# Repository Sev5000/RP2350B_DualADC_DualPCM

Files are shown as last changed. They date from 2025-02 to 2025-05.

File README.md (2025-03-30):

# RP2350B_DualADC_DualPCM
This is a PCB to neatly package a RP2350B, two AD9226 ADC PCBs and two PCM1802 audio boards for capture with hsdaoh.
Specifically designed to still be usefull without smds (no head switch input then). Through-hole soldering only works just fine.

For use with [https://github.com/steve-m/hsdaoh-rp2350/tree/pcm1802](https://github.com/steve-m/hsdaoh/tree/dual_12bit_adc)

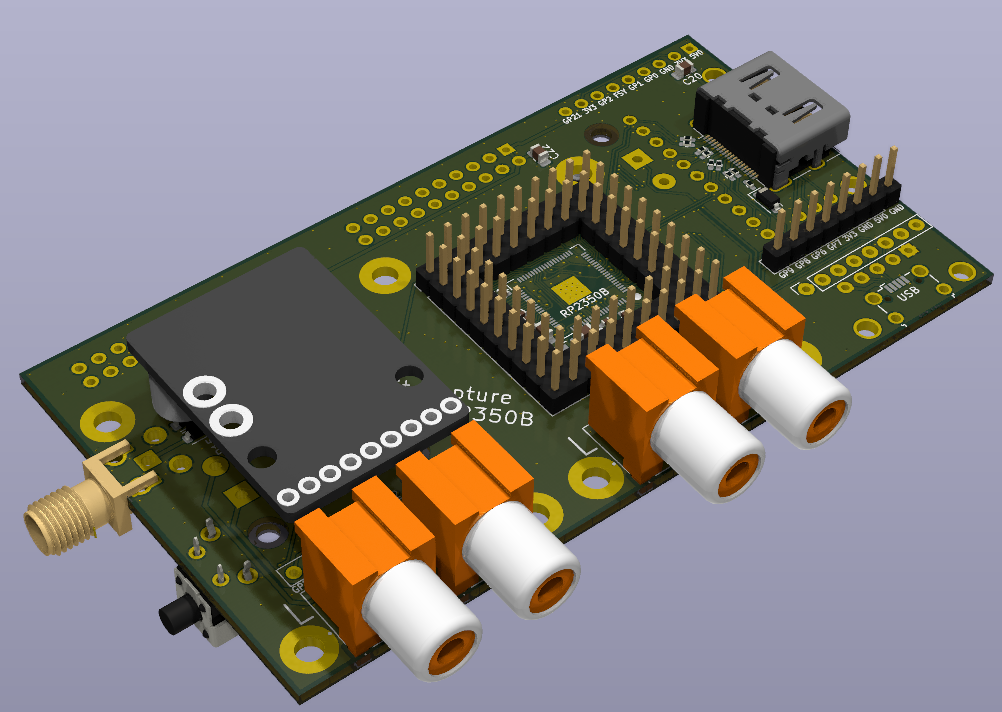
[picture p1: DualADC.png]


Features:
- Two 12bit 40MS/s ADCs
- Four channel audio input all with a common clock
- No SMD soldering needed! Works fine just connecting breakout boards
- Socket for a Pimoroni PGA2350 and RP2350 and its periphery
- The protected head switch input has footprints for edge and horizontal SMA/SMB (SMD soldering needed)
- Socket for USB C and Micro B breakouts
  
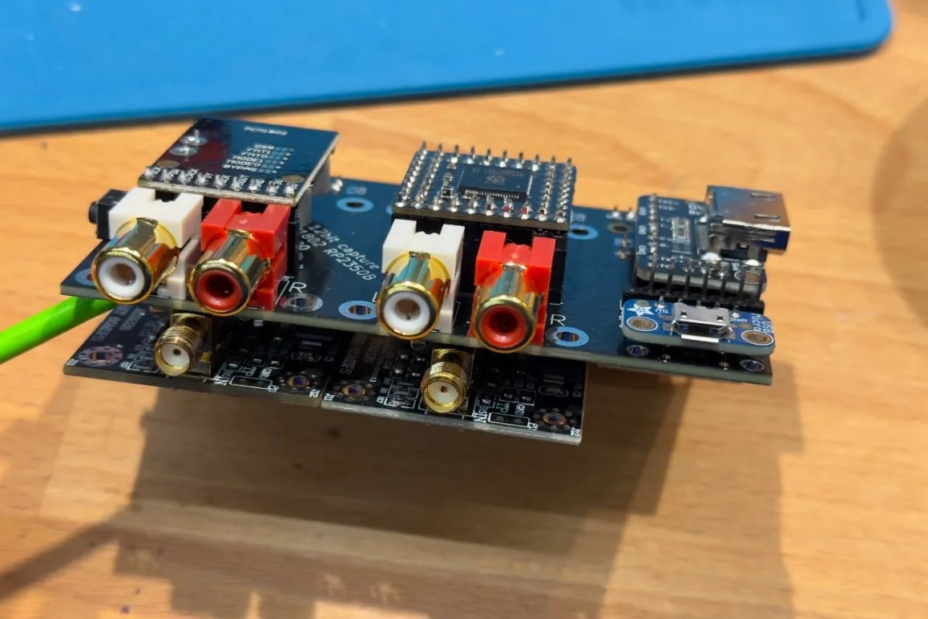
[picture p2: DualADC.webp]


Bill of material: 
- 1x This PCB (Send the Gerber .zip to JLC, PCBWay, ..)
- 1x Pimoroni PGA2350
- 2x AD9226: https://aliexpress.com/item/1005003038271519.html
- 2x PCM1802: https://aliexpress.com/item/1005006412873984.html
- 4x RCA-105 or RCA-106: https://aliexpress.com/item/1005006152724809.html
- 2x 9pin 2.54mm pin-socket header 
- 2x 2x10pin 2.54mm pin-socket header
- 2x 3pin 2.54mm pin header (remove the center pin for connecting R/L of the PCM1802)
- 2x 3pin 2.54mm pin-socket header (remove the center pin for connecting R/L of the PCM1802)
- 1x vertical 6mm push button: https://aliexpress.com/item/1005005831153897.html (horizontal soldered in vertical and a drop of glue for stability works as well)

No SMD variant:
- 1x Adafruit DVI breakout board
- 4x 2x8pin 2.54mm pin-socket header
- Either Adafruit USB Micro-B Breakout Board or Adafruit USB C Breakout Board

SMD Variant with PGA2350:
- Regular HDMI connector
- micro USB connector
- 8× 0402 270 ohm resistors
- 4x 0805 100nF ceramic capacitors
- For experimental EDID communication and HPD: 4x SOD123 3.3V Zener, 4x 0402 ~27 ohm resistors, 2x 0402 2k2 ohm resistors

For head switch input:
- 1x SOD123 3.3V zener diode
- 1x SOD123 standard diode
- 1x 0805 1k resistor
- 1x edge SMA/SMB or horizontal SMA/SMB and/or 2pin header

Notes:
- Soldering the RP2350B and its periphery might work but was not tested so far.
- The PCM1802 board needs MODE0 (MODE1 only with previous HSDAOH releases) bridged *and* connected to 3.3V with a wire (Those boards have a design error):
NOTE: Picture shows the configuration for the older firmware, now only MODE0 needs to be bridged and connected to 3.3V



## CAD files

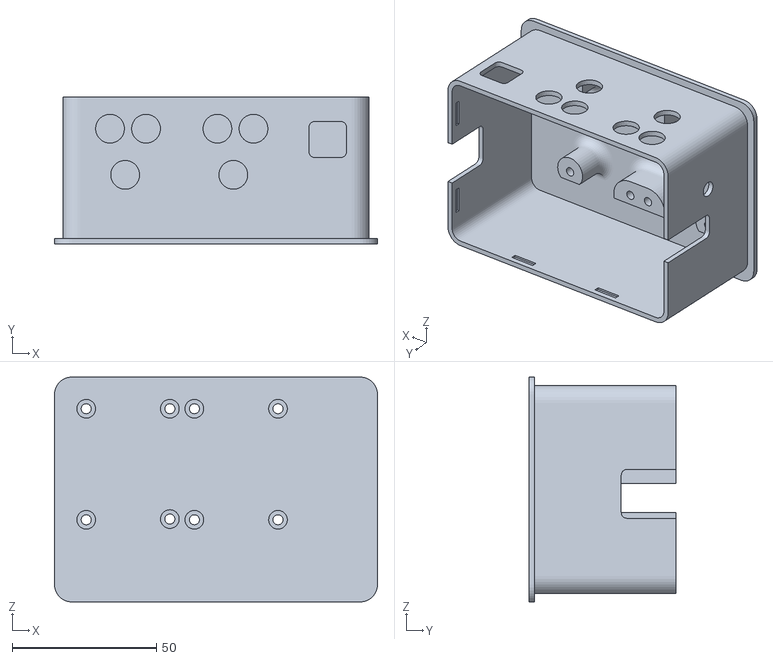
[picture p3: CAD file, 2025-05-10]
Case/RPi2350_Dual_Base.stl
112.0 x 51.0 x 78.0

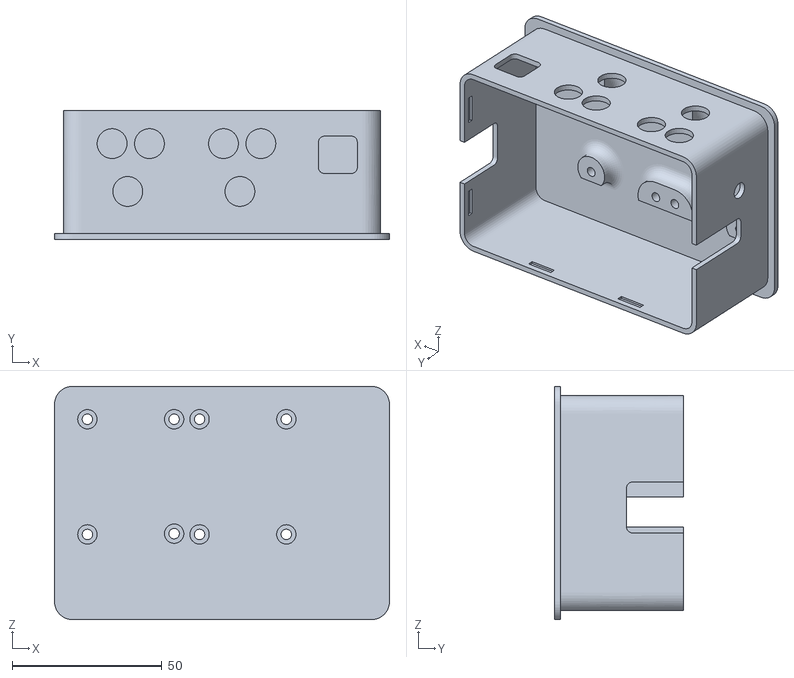
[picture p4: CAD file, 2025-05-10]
Case/RPi2350_Dual_Base_LowProfile.stl
112.0 x 43.0 x 78.0

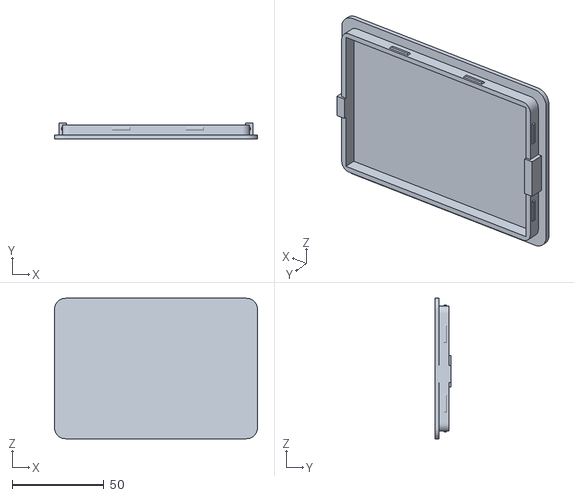
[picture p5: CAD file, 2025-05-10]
Case/RPi2350_Dual_Lid.stl
110.5 x 8.50 x 76.5

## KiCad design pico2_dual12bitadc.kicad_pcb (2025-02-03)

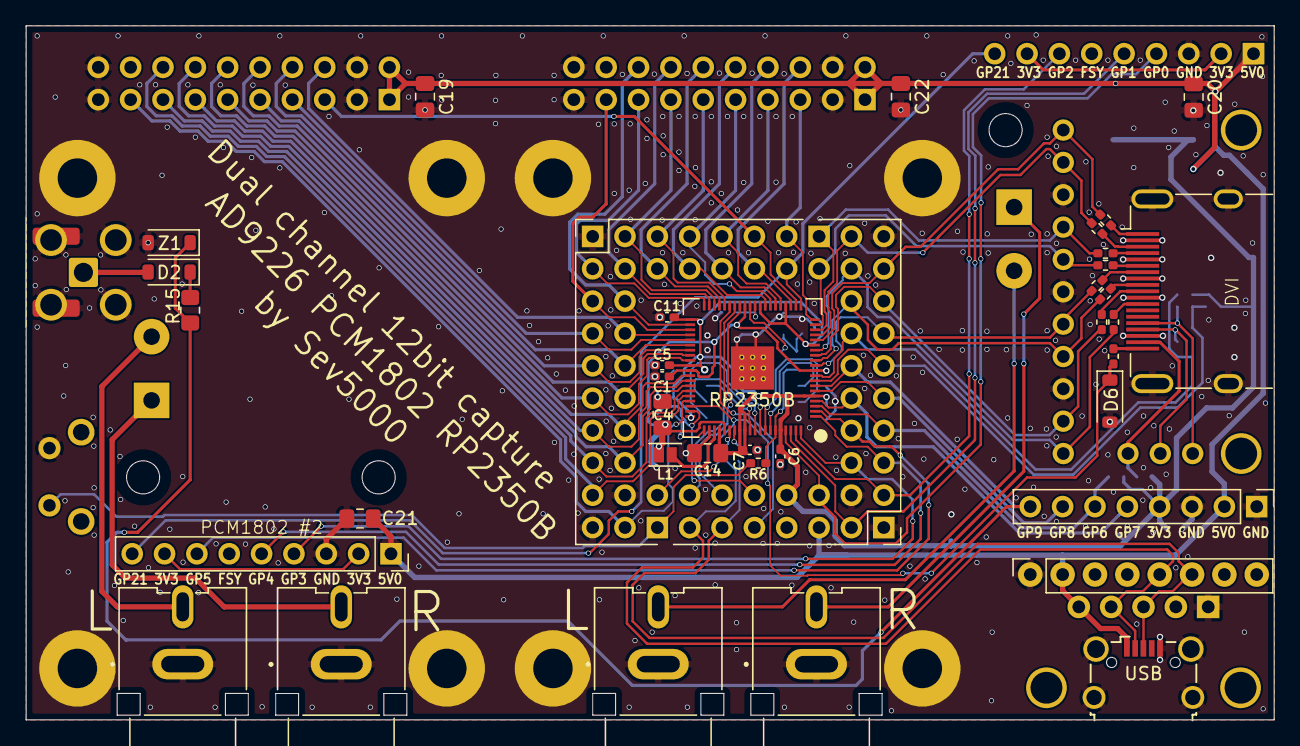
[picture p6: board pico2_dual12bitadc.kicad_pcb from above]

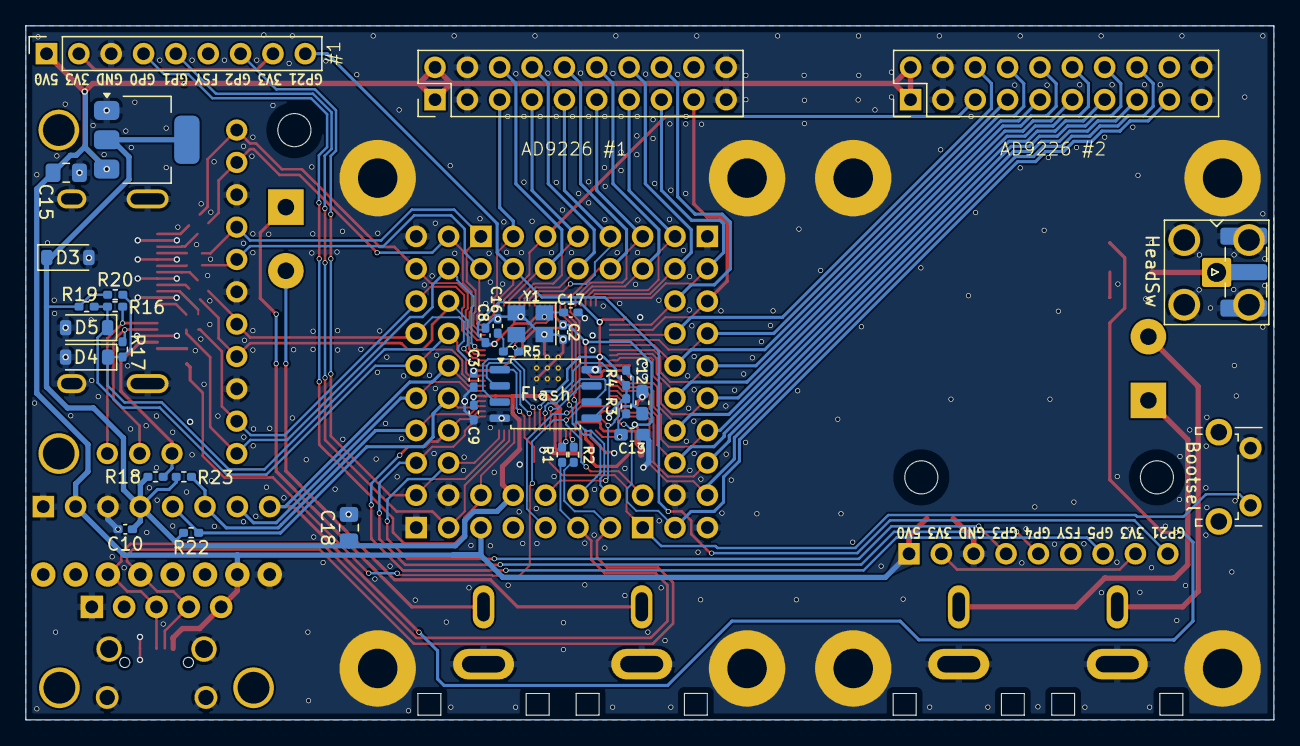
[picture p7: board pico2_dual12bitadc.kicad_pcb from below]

Board: 2 copper layers, 98.0 x 54.5 mm, 75 parts (34 on the bottom side), 89 nets.

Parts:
AD9226 #1: AD9226 #1; AD9226 PCB
AD9226 #2: AD9226 #2; AD9226 PCB
Bootsel: SW_Push; SW_Tactile_SPST_Angled_PTS645Vx58-2LFS
C1, C2, C3, C5, C6, C7, C8, C9, C10, C11: 100nF; C_0402_1005Metric_Pad0.74x0.62mm_HandSolder
C4, C14, C15: 10uF; C_0805_2012Metric_Pad1.18x1.45mm_HandSolder
C12, C13: 2.2uF; C_0603_1608Metric_Pad1.08x0.95mm_HandSolder
C16, C17: 15pF; C_0402_1005Metric_Pad0.74x0.62mm_HandSolder
C18: 4.7uF; C_0805_2012Metric_Pad1.18x1.45mm_HandSolder
C19, C20, C21, C22: 100nF; C_0805_2012Metric_Pad1.18x1.45mm_HandSolder
D2: D; D_SOD-123
D3, D4, D5, D6: D_Zener3.3V; D_SOD-123
DVI: DVI Breakout; Adafruit DVI Breakout
Flash: W25Q128JVS; SOIC-8_5.23x5.23mm_P1.27mm
GP9 GP8 GP6 GP7 3V3 GND 5V0 GND: Aux Connector; PinHeader_1x08_P2.54mm_Vertical
HeadSw: SMAEdge; SMA_Samtec_SMA-J-P-H-ST-EM1_EdgeMount
J1: PGA2350 Left; PinHeader_2x10_P2.54mm_Vertical
J2: PGA2350 Right; PinHeader_2x10_P2.54mm_Vertical
J3: PGA2350 Bottom; PinHeader_2x06_P2.54mm_Vertical
J4: PGA2350 Top; PinHeader_2x06_P2.54mm_Vertical
J6: HDMI_A; HDMI_A_Molex_208658-1001_Horizontal
J11: Adafruit USB-C and Micro Breakout; Adafruit USB C and Micro Breakout
J12: SMA90; SMA_Amphenol_901-143_Horizontal
L: L; CUI_RCJ-047
L1: 3.3uH; L_TDK_MLZ2012_h1.25mm
L#2: L; CUI_RCJ-047
PCM1802 #2: PCM1802 #2; PCM1802 PCB
R: R; CUI_RCJ-047
R1, R2, R3, R16, R17, R18, R21: 27R4; R_0402_1005Metric_Pad0.72x0.64mm_HandSolder
R4: 220; R_0402_1005Metric_Pad0.72x0.64mm_HandSolder
R5, R6: 1k; R_0402_1005Metric_Pad0.72x0.64mm_HandSolder
R7, R8, R9, R10, R11, R12, R13, R14: 270; R_0402_1005Metric_Pad0.72x0.64mm_HandSolder
R15: 1k; R_0805_2012Metric_Pad1.20x1.40mm_HandSolder
R19, R20, R22, R23: 2k2; R_0402_1005Metric_Pad0.72x0.64mm_HandSolder
R#2: R; CUI_RCJ-047
RP2350B: RP2350B-QFN80; RP2350B_QFN-80_EP_10.573x10.573_Pitch0.4mm
U1: NCP1117-3.3_SOT223; SOT-223-3_TabPin2
USB: USB_B_Micro; USB_Micro-B_Wuerth_629105150521_CircularHoles
Y1: ABM8-272-T3; Crystal_SMD_Abracon_ABM8G-4Pin_3.2x2.5mm
Z1: D_Zener3.3V; D_SOD-123

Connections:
+1V1: C1.1, C2.1, C3.1, C4.1, L1.2, RP2350B.10 (DVDD), RP2350B.32 (DVDD), RP2350B.51 (DVDD), RP2350B.65 (VREG_FB)
+3V3: C5.1, C6.1, C7.1, C8.1, C9.1, C10.1, C11.1, C14.1, C18.1, D3.1 (K), Flash.8 (VCC), GP9 GP8 GP6 GP7 3V3 GND 5V0 GND.4 (3V3), J4.10, R3.2, R4.1, R18.2, R19.2, R20.1, R22.2, R23.1, RP2350B.5 (IOVDD), RP2350B.15 (IOVDD), RP2350B.24 (IOVDD), RP2350B.29 (IOVDD), RP2350B.41 (IOVDD), RP2350B.50 (IOVDD), RP2350B.60 (IOVDD), RP2350B.64 (VREG_VIN), RP2350B.68 (USB_OTP_VDD), RP2350B.69 (QSPI_IOVDD), RP2350B.76 (IOVDD), U1.2 (VO)
/ADC VREF: C12.1, J4.8, R4.2, RP2350B.59 (ADC_AVDD)
/BOOTSEL: Bootsel.2, J4.1, R6.2
/CK+: DVI.10 (CK+), J1.15, R13.1, RP2350B.13 (GPIO14)
/CK-: DVI.12 (CK-), J1.18, R14.1, RP2350B.14 (GPIO15)
/D0+: DVI.7 (D0+), J1.13, R11.1, RP2350B.11 (GPIO12)
/D0-: DVI.9 (D0-), J1.16, R12.1, RP2350B.12 (GPIO13)
/D1+: DVI.4 (D1+), J3.1, R9.1, RP2350B.18 (GPIO18)
/D1-: DVI.6 (D1-), J3.2, R10.1, RP2350B.19 (GPIO19)
/D2+: DVI.1 (D2+), J1.17, R7.1, RP2350B.16 (GPIO16)
/D2-: DVI.3 (D2-), J1.20, R8.1, RP2350B.17 (GPIO17)
/GPIO0: J4.12, RP2350B.77 (GPIO0)
/GPIO1: J1.2, RP2350B.78 (GPIO1)
/GPIO2: J1.3, RP2350B.79 (GPIO2)
/GPIO3: J1.6, PCM1802 #2.4 (DOUT), RP2350B.80 (GPIO3)
/GPIO4: J1.5, PCM1802 #2.5 (BCK), RP2350B.1 (GPIO4)
/GPIO5: J1.8, PCM1802 #2.7 (LRCK), RP2350B.2 (GPIO5)
/GPIO6: GP9 GP8 GP6 GP7 3V3 GND 5V0 GND.6 (GP6/SDA), J1.7, R23.2, RP2350B.3 (GPIO6)
/GPIO7: GP9 GP8 GP6 GP7 3V3 GND 5V0 GND.5 (GP7/SCL), J1.10, R22.1, RP2350B.4 (GPIO7)
/GPIO8: GP9 GP8 GP6 GP7 3V3 GND 5V0 GND.7 (GP8), J1.9, RP2350B.6 (GPIO8)
/GPIO9: GP9 GP8 GP6 GP7 3V3 GND 5V0 GND.8 (GP9/HeadSw), J1.12, R15.2, RP2350B.7 (GPIO9), Z1.1 (K)
/GPIO10: D5.1 (K), J1.11, R16.1, R19.1, RP2350B.8 (GPIO10)
/GPIO11: D4.1 (K), J1.14, R17.1, R20.2, RP2350B.9 (GPIO11)
/GPIO20: AD9226 #1.5, J3.3, RP2350B.20 (GPIO20)
/GPIO21: J3.4, PCM1802 #2.9 (SCK), RP2350B.21 (GPIO21)
/GPIO22: AD9226 #2.5, J3.5, RP2350B.22 (GPIO22)
/GPIO23: AD9226 #1.6, J3.6, RP2350B.23 (GPIO23)
/GPIO24: AD9226 #1.7, J3.7, RP2350B.25 (GPIO24)
/GPIO25: AD9226 #1.8, J3.8, RP2350B.26 (GPIO25)
/GPIO26: AD9226 #1.9, J3.9, RP2350B.27 (GPIO26)
/GPIO27: AD9226 #1.10, J3.10, RP2350B.28 (GPIO27)
/GPIO28: AD9226 #1.11, J3.11, RP2350B.36 (GPIO28)
/GPIO29: AD9226 #1.12, J3.12, RP2350B.37 (GPIO29)
/GPIO30: AD9226 #1.13, J2.2, RP2350B.38 (GPIO30)
/GPIO31: AD9226 #1.14, J2.4, RP2350B.39 (GPIO31)
/GPIO32: AD9226 #1.15, J2.3, RP2350B.40 (GPIO32)
/GPIO33: AD9226 #1.16, J2.6, RP2350B.42 (GPIO33)
/GPIO34: AD9226 #1.17, J2.5, RP2350B.43 (GPIO34)
/GPIO35: AD9226 #2.6, J2.8, RP2350B.44 (GPIO35)
/GPIO36: AD9226 #2.7, J2.7, RP2350B.45 (GPIO36)
/GPIO37: AD9226 #2.8, J2.10, RP2350B.46 (GPIO37)
/GPIO38: AD9226 #2.9, J2.9, RP2350B.47 (GPIO38)
/GPIO39: AD9226 #2.10, J2.12, RP2350B.48 (GPIO39)
/GPIO40: AD9226 #2.11, J2.11, RP2350B.49 (GPIO40_ADC0)
/GPIO41: AD9226 #2.12, J2.14, RP2350B.52 (GPIO41_ADC1)
/GPIO42: AD9226 #2.13, J2.13, RP2350B.53 (GPIO42_ADC2)
/GPIO43: AD9226 #2.14, J2.16, RP2350B.54 (GPIO43_ADC3)
/GPIO44: AD9226 #2.15, J2.15, RP2350B.55 (GPIO44_ADC4)
/GPIO45: AD9226 #2.16, J2.17, RP2350B.56 (GPIO45_ADC5)
/GPIO46: AD9226 #2.17, J2.20, RP2350B.57 (GPIO46_ADC6)
/GPIO47: D6.1 (K), J4.2, R21.2, RP2350B.58 (GPIO47_ADC7)
/L: L1.1, RP2350B.63 (VREG_LX)
/RUN: J4.7, RP2350B.35 (RUN)
/SWCLK: J4.6, RP2350B.33 (SWCLK)
/SWDIO: J4.4, RP2350B.34 (SWDIO)
/USB_D+: J4.5, J11.6 (D+), R1.2, USB.3 (D+)
/USB_D-: J4.3, J11.5 (D-), R2.2, USB.2 (D-)
GND: AD9226 #1.3, AD9226 #1.4, AD9226 #1.19, AD9226 #1.20, AD9226 #2.3, AD9226 #2.4, AD9226 #2.19, AD9226 #2.20, Bootsel.1, C1.2, C2.2, C3.2, C4.2, C5.2, C6.2, C7.2, C8.2, C9.2, C10.2, C11.2, C12.2, C13.2, C14.2, C15.2, C16.1, C17.2, C18.2, C19.2, C20.2, C21.2, C22.2, D3.2 (A), D4.2 (A), D5.2 (A), D6.2 (A), DVI.17 (GND), Flash.4 (GND), GP9 GP8 GP6 GP7 3V3 GND 5V0 GND.1 (GND), GP9 GP8 GP6 GP7 3V3 GND 5V0 GND.3 (GND), HeadSw.2 (Ext), J1.1, J1.4, J1.19, J2.1, J2.18, J2.19, J6.2 (D2S), J6.5 (D1S), J6.8 (D0S), J6.11 (CKS), J6.17 (GND), J6.SH, J11.1 (GND), J12.2 (Ext), L.2 (Ext), L#2.2 (Ext), PCM1802 #2.3 (GND), R.2 (Ext), R#2.2 (Ext), RP2350B.62 (VREG_PGND), RP2350B.81 (GND), U1.1 (GND), USB.5 (GND), USB.6 (Shield), Y1.2, Y1.4, Z1.2 (A)
unnamed: C16.2, R5.2, Y1.3
unnamed: D2.2 (A), HeadSw.1 (In), J12.1 (In)
unnamed: D2.1 (K), R15.1
unnamed: J6.10 (CK+), R13.2
unnamed: J6.12 (CK-), R14.2
unnamed: J6.7 (D0+), R11.2
unnamed: J6.9 (D0-), R12.2
unnamed: J6.4 (D1+), R9.2
unnamed: J6.6 (D1-), R10.2
unnamed: J6.1 (D2+), R7.2
unnamed: J6.3 (D2-), R8.2
unnamed: PCM1802 #2.2 (3.3V), PCM1802 #2.8 (PDW)
unnamed: DVI.18 (+5V), J6.18 (+5V), R18.1
unnamed: J6.19 (HPD), R21.1
unnamed: DVI.15 (SCL), J6.15 (SCL), R16.2
unnamed: DVI.16 (SDA), J6.16 (SDA), R17.2
unnamed: PCM1802 #2.10 (Rin), R#2.1 (In)
unnamed: L.1 (In), PCM1802 #2.11 (Lin)
unnamed: Flash.6 (CLK), RP2350B.71 (QSPI_SCLK)
unnamed: Flash.5 (DI(IO0)), RP2350B.72 (QSPI_SD0)
unnamed: Flash.2 (DO(IO1)), RP2350B.74 (QSPI_SD1)
unnamed: Flash.3 (IO2), RP2350B.73 (QSPI_SD2)
unnamed: Flash.7 (IO3), RP2350B.70 (QSPI_SD3)
unnamed: Flash.1 (~CS), R6.1, RP2350B.75 (QSPI_SS)
unnamed: R2.1, RP2350B.66 (USB_DM)
unnamed: R1.1, RP2350B.67 (USB_DP)
unnamed: C13.1, R3.1, RP2350B.61 (VREG_AVDD)
unnamed: C17.1, RP2350B.30 (XIN), Y1.1
unnamed: R5.1, RP2350B.31 (XOUT)
VBUS: AD9226 #1.1, AD9226 #1.2, AD9226 #2.1, AD9226 #2.2, C15.1, C19.1, C20.1, C21.1, C22.1, GP9 GP8 GP6 GP7 3V3 GND 5V0 GND.2 (VBUS), J4.11, J11.2 (VBUS), PCM1802 #2.1 (5V), U1.3 (VI), USB.1 (VBUS)

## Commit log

2025-02-03 Initial upload
    [pico2_dual12bitadc.kicad_pcb, pico2_dual12bitadc.kicad_sch]
2025-04-21 3D Printable Case
    - Added 3D printable case, with low profile variant for devices with removed bottom connector.
    [RPi2350_Dual_Base.stl, RPi2350_Dual_Base_LowProfile.stl, RPi2350_Dual_Lid.stl]
